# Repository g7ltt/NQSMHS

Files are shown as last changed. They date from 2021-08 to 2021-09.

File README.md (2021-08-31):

# NQSMHS

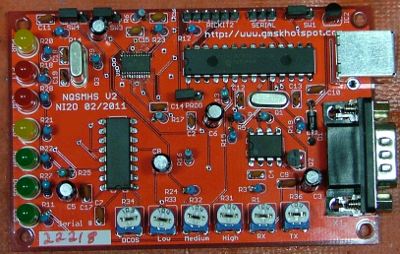
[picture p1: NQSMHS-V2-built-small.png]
finished board


Home of the D-STAR™ compatible Mini-HotSpot & Not Quite So Mini-HotSpot

Similar to the NQSMHS V1.1x series, the V2 board shares all the same facilities. The only changes are mechanical/cosmetic and with a few circuit flaws repaired.

Features include
Digital COS
DUTCH*Star HSA firmware compatible
"Satoshi" firmware V4.xx and V5.xx compatible
TTL serial port (for slow speed data)
S:N/RSSI (when used with relevant firmware/software)
USB firmware boot loader (when used with relevant firmware)
PICKit2 ICSP header
The NQSMHS-V2 is available in kit format. Lead time is usually 1 week but may change due to parts availability.

Unlike the 1.1x series of boards firmware is now provided Your board comes supplied with the DUTCH*Star PICBoot bootloader pre-installed. This will enable you to install the DUTCH*Star HSA firmware available from http://www.dutch-star.eu when coupled with the supplied firmware licence key.

REV V2
Nothing to report. All works as planned (when did that ever happen?!)

Please refer to the DUTCH*Star documentation for instructions on installing the firmware and drivers.

DIP switch settings are as follows;
SW1 (power)          Left = USB powered     Right = external 12V powered
PROG            installed = force bootloader mode
SW3               installed = RSSI enabled
SW4                       Left = RSSI enabled       Right = RSSI disabled
 Board layout, schematic and parts list can be found here.

MODS
Some users report very low transmit data levels emitting from the board. A quick fix for this is to cut the right leg of the TX pot.

Some users have reported that the PTT remains keyed long after the data has gone. This appears to be RF feedback holding the PTT transitor open. Place a 100pF (101) cap between the base of Q2 ground.

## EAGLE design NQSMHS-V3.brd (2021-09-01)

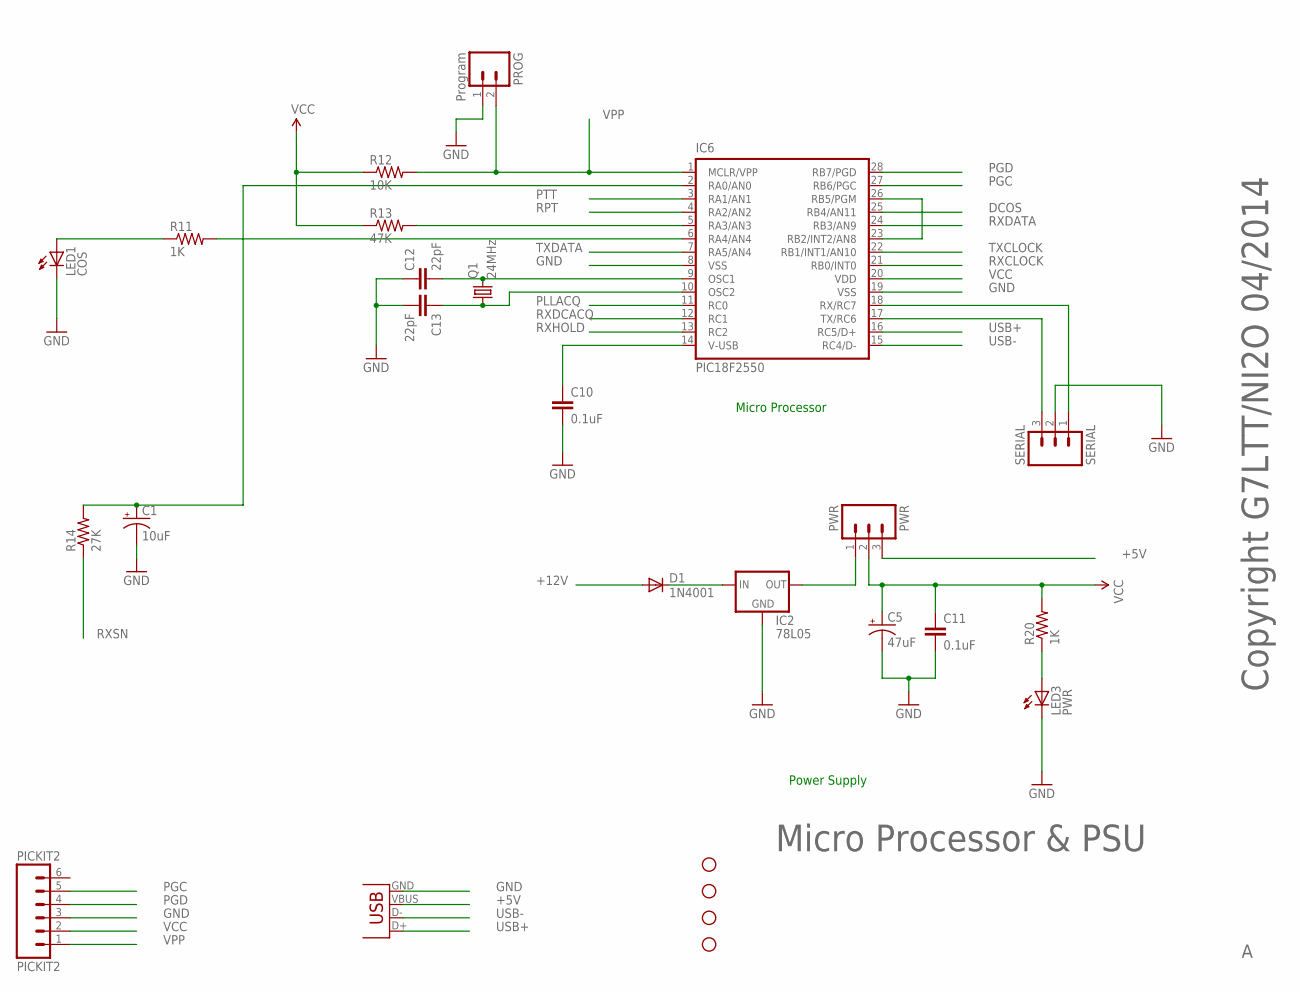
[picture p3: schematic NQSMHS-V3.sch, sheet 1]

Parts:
C1: 10uF; CPOL-RADIAL-10UF-25V
C5: 47uF; CPOL-RADIAL-10UF-25V
C10, C11: 0.1uF; C2.5-2
C12, C13: 22pF; C2.5-2
D1: 1N4001; DIODE-1N4001
IC2: 78L05; 78LXX
IC6: PIC18F2550; DIL28-3
J1: USBPTH; USB-B-PTH
JP7, JP8, JP9, JP10: STAND-OFF
LED1: COS; LED3MM
LED3: PWR; LED3MM
PICKIT2: PICKIT2; 1X06
PROG: Program; 1X02
PWR: PWR; 1X03
Q1: 24MHz; HC49US
R11, R20: 1K; 0207/2V
R12: 10K; 0207/2V
R13: 47K; 0207/2V
R14: 27K; 0207/2V
SERIAL: SERIAL; 1X03

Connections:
+5V: J1.VBUS, PWR.3
+12V: D1.A; also elsewhere on the board
DCOS: IC6.25 (RB4/AN11); also elsewhere on the board
GND: C1.2 (-), C5.2 (-), C10.2, C11.2, C12.1, C13.2, IC2.GND, IC6.8 (VSS), IC6.19 (VSS), J1.GND, LED1.K (C), LED3.K (C), PICKIT2.3, PROG.1, SERIAL.2; also elsewhere on the board
unnamed: D1.C, IC2.IN
unnamed: IC6.23 (RB2/INT2/AN8), IC6.26 (RB5/PGM)
unnamed: IC6.5 (RA3/AN3), R13.2
unnamed: IC6.6 (RA4/AN4), R11.2
unnamed: LED1.A, R11.1
unnamed: C12.2, IC6.9 (OSC1), Q1.2
unnamed: C13.1, IC6.10 (OSC2), Q1.1
unnamed: C10.1, IC6.14 (V-USB)
unnamed: IC2.OUT, PWR.1
unnamed: LED3.A, R20.1
PGC: IC6.27 (RB6/PGC), PICKIT2.5
PGD: IC6.28 (RB7/PGD), PICKIT2.4
PLLACQ: IC6.11 (RC0); also elsewhere on the board
PTT: IC6.3 (RA1/AN1); also elsewhere on the board
RPT: IC6.4 (RA2/AN2)
RX-232: IC6.18 (RX/RC7), SERIAL.1
RXCLOCK: IC6.21 (RB0/INT0); also elsewhere on the board
RXDATA: IC6.24 (RB3/AN9); also elsewhere on the board
RXDCACQ: IC6.12 (RC1); also elsewhere on the board
RXHOLD: IC6.13 (RC2); also elsewhere on the board
RXSN: R14.1; also elsewhere on the board
TX-232: IC6.17 (TX/RC6), SERIAL.3
TX/SN: C1.1 (+), IC6.2 (RA0/AN0), R14.2
TXCLOCK: IC6.22 (RB1/INT1/AN10); also elsewhere on the board
TXDATA: IC6.7 (RA5/AN4); also elsewhere on the board
USB+: IC6.16 (RC5/D+), J1.D+
USB-: IC6.15 (RC4/D-), J1.D-
VCC: C5.1 (+), C11.1, IC6.20 (VDD), PICKIT2.2, PWR.2, R12.1, R13.1, R20.2; also elsewhere on the board
VPP: IC6.1 (MCLR/VPP), PICKIT2.1, PROG.2, R12.2

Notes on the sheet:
Power Supply
Micro Processor
Micro Processor & PSU
Copyright G7LTT/NI2O 04/2014

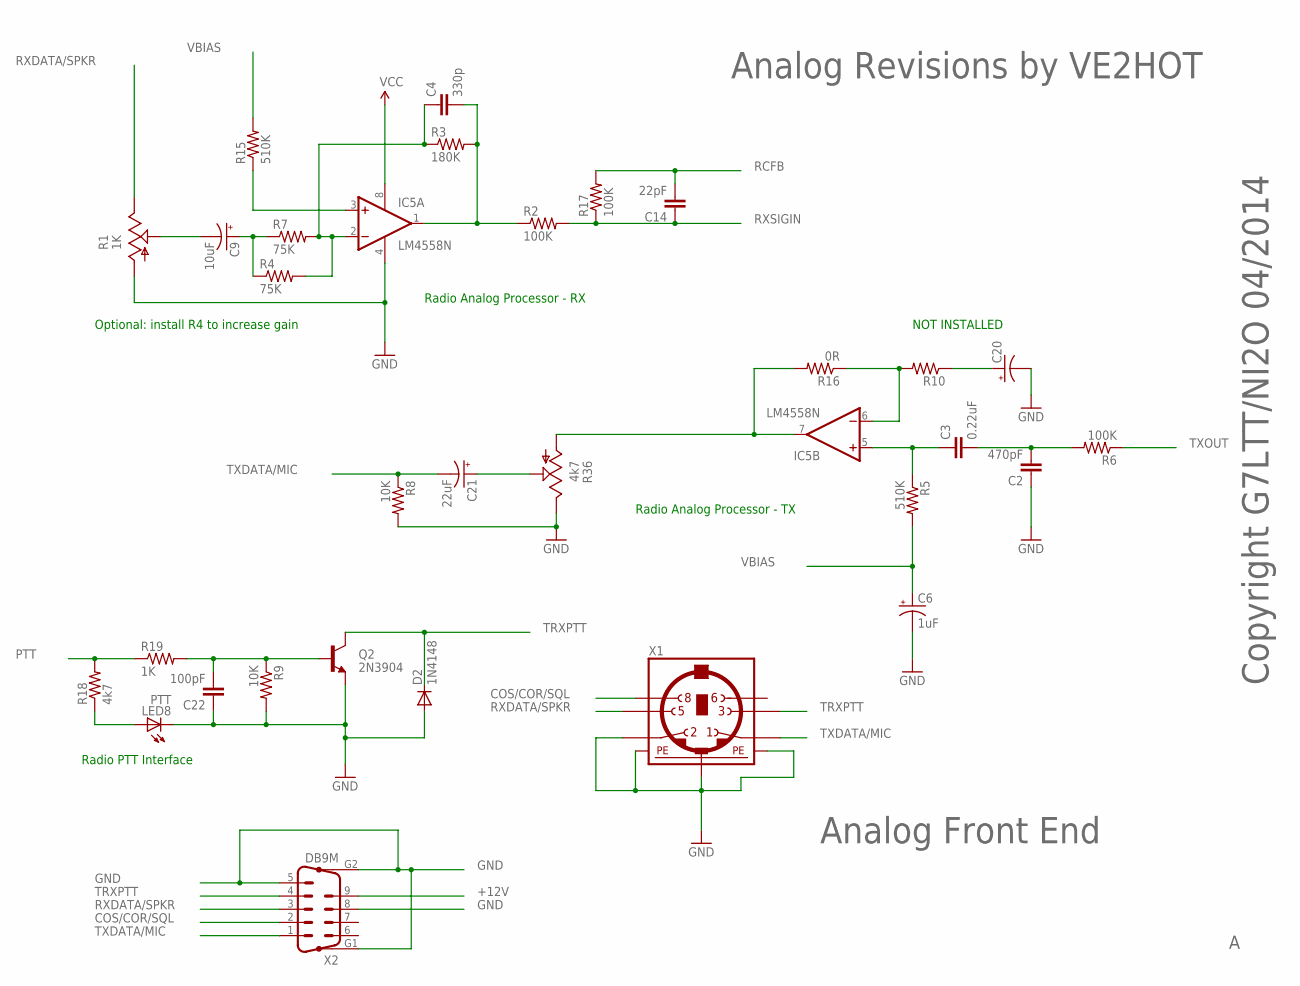
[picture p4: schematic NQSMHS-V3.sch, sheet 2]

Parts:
C2: 470pF; C2.5-2
C3: 0.22uF; C2.5-2
C4: 330p; C2.5-2
C6: 1uF; CPOL-RADIAL-10UF-25V
C9: 10uF; CPOL-RADIAL-10UF-25V
C14: 22pF; C2.5-2
C20: CAP_POLPTH2; CPOL-RADIAL-10UF-25V
C21: 22uF; CPOL-RADIAL-10UF-25V
C22: 100pF; C2.5-2
D2: 1N4148; DO35-10
IC5: LM4558N; DIL08
LED8: PTT; LED3MM
Q2: 2N3904; TO-92
R1: 1K; CA6V
R2, R6, R17: 100K; 0207/2V
R3: 180K; 0207/2V
R4, R7: 75K; 0207/2V
R5, R15: 510K; 0207/2V
R8, R9: 10K; 0207/2V
R10: R-US_0207/2V; 0207/2V
R16: 0R; 0207/2V
R18: 4k7; 0207/2V
R19: 1K; 0207/2V
R36: 4k7; CA6V
X1: MINI_DIN_6; M_DIN6
X2: DB9M; M09HP

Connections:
+12V: X2.9; also elsewhere on the board
COS/COR/SQL: X1.8, X2.2
GND: C2.1, C6.2 (-), C20.2 (-), C22.1, D2.A, IC5.4 (V-), LED8.K (C), Q2.1 (E), R1.A, R8.2, R9.2, R36.E, X1.2, X1.SH1 (PE1), X1.SH2 (PE2), X1.SH3 (PE3), X2.5, X2.8, X2.G1, X2.G2; also elsewhere on the board
unnamed: C2.2, C3.2, R6.2
unnamed: C22.2, Q2.2 (B), R9.1, R19.2
unnamed: LED8.A, R18.1
unnamed: C9.2 (-), R1.S
unnamed: IC5.7 (OUT), R16.2, R36.A
unnamed: C9.1 (+), R4.1, R7.1
unnamed: C4.2, IC5.1 (OUT), R2.1, R3.2
unnamed: C3.1, IC5.5 (+IN), R5.1
unnamed: C4.1, IC5.2 (-IN), R3.1, R4.2, R7.2
unnamed: IC5.6 (-IN), R10.2, R16.1
unnamed: C20.1 (+), R10.1
unnamed: C21.1 (+), R36.S
unnamed: IC5.3 (+IN), R15.1
PTT: R18.2, R19.1; also elsewhere on the board
RCFB: C14.2, R17.2; also elsewhere on the board
RXDATA/SPKR: R1.E, X1.5, X2.3
RXSIGIN: C14.1, R2.2, R17.1; also elsewhere on the board
TRXPTT: D2.C, Q2.3 (C), X1.3, X2.4
TXDATA/MIC: C21.2 (-), R8.1, X1.1, X2.1
TXOUT: R6.1; also elsewhere on the board
VBIAS: C6.1 (+), R5.2, R15.2; also elsewhere on the board
VCC: IC5.8 (V+); also elsewhere on the board

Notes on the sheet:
Radio Analog Processor - RX
Radio PTT Interface
Radio Analog Processor - TX
Analog Front End
Copyright G7LTT/NI2O 04/2014
Analog Revisions by VE2HOT
Optional: install R4 to increase gain
NOT INSTALLED

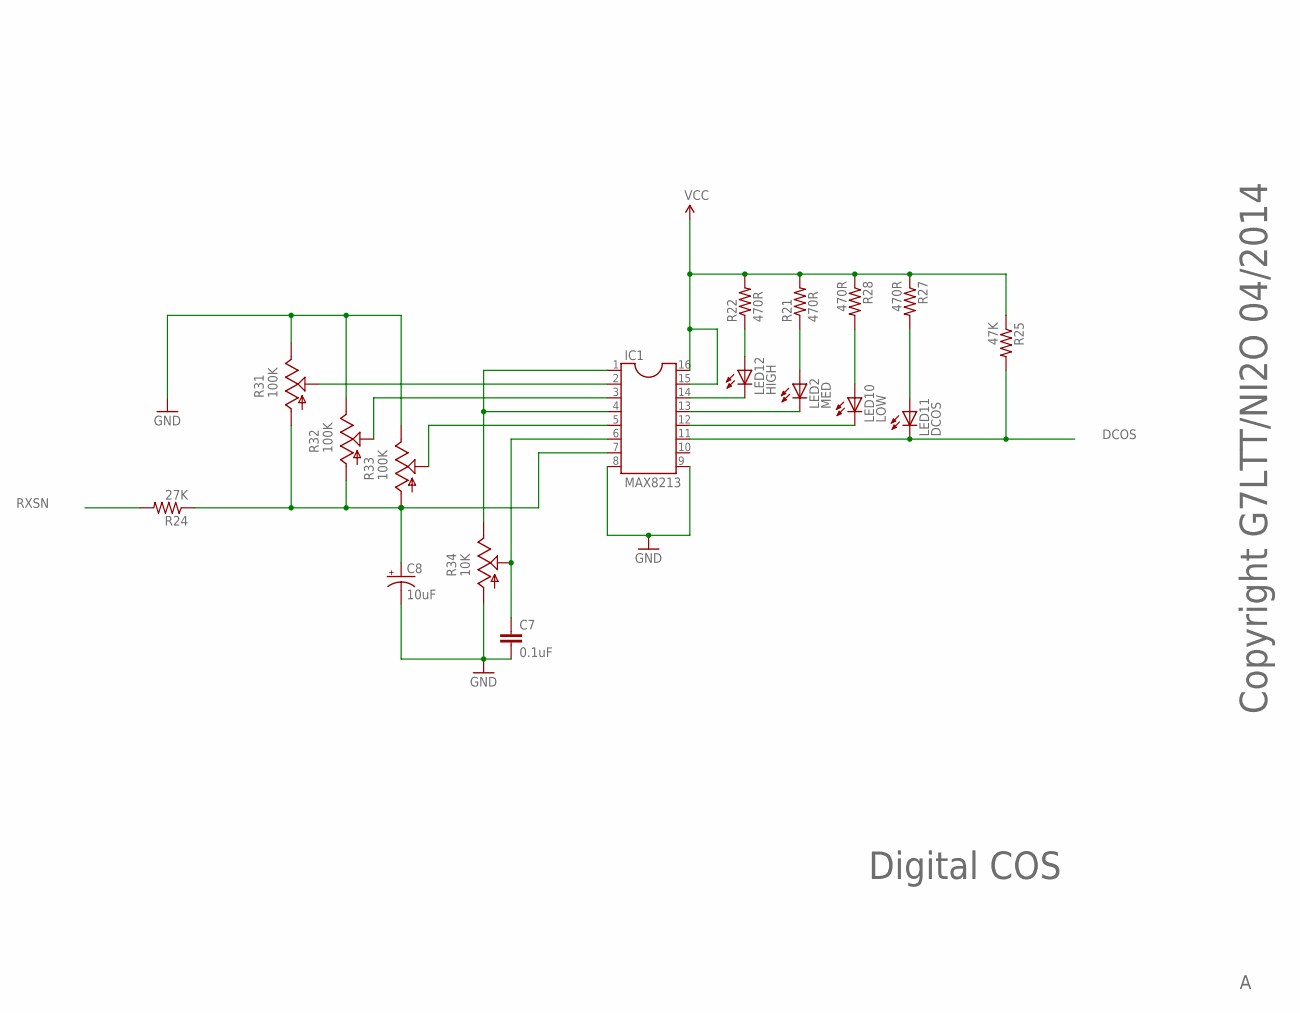
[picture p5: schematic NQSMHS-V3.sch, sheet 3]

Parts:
C7: 0.1uF; C2.5-2
C8: 10uF; CPOL-RADIAL-10UF-25V
IC1: MAX8213; DIL16
LED2: MED; LED3MM
LED10: LOW; LED3MM
LED11: DCOS; LED3MM
LED12: HIGH; LED3MM
R21, R22, R27, R28: 470R; 0207/2V
R24: 27K; 0207/2V
R25: 47K; 0207/2V
R31, R32, R33: 100K; CA6V
R34: 10K; CA6V

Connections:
DCOS: IC1.11, LED11.K (C), R25.2; also elsewhere on the board
GND: C7.2, C8.2 (-), IC1.8, IC1.9, R31.E, R32.E, R33.E, R34.A; also elsewhere on the board
unnamed: C7.1, IC1.6, R34.S
unnamed: IC1.14, LED12.K (C)
unnamed: LED12.A, R22.1
unnamed: IC1.13, LED2.K (C)
unnamed: LED2.A, R21.1
unnamed: IC1.12, LED10.K (C)
unnamed: LED11.A, R27.2
unnamed: LED10.A, R28.2
unnamed: IC1.2, R31.S
unnamed: IC1.3, R32.S
unnamed: IC1.5, R33.S
unnamed: IC1.1, IC1.4, R34.E
unnamed: C8.1 (+), IC1.7, R24.1, R31.A, R32.A, R33.A
RXSN: R24.2; also elsewhere on the board
VCC: IC1.15, IC1.16, R21.2, R22.2, R25.1, R27.1, R28.1; also elsewhere on the board

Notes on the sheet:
Digital COS
Copyright G7LTT/NI2O 04/2014

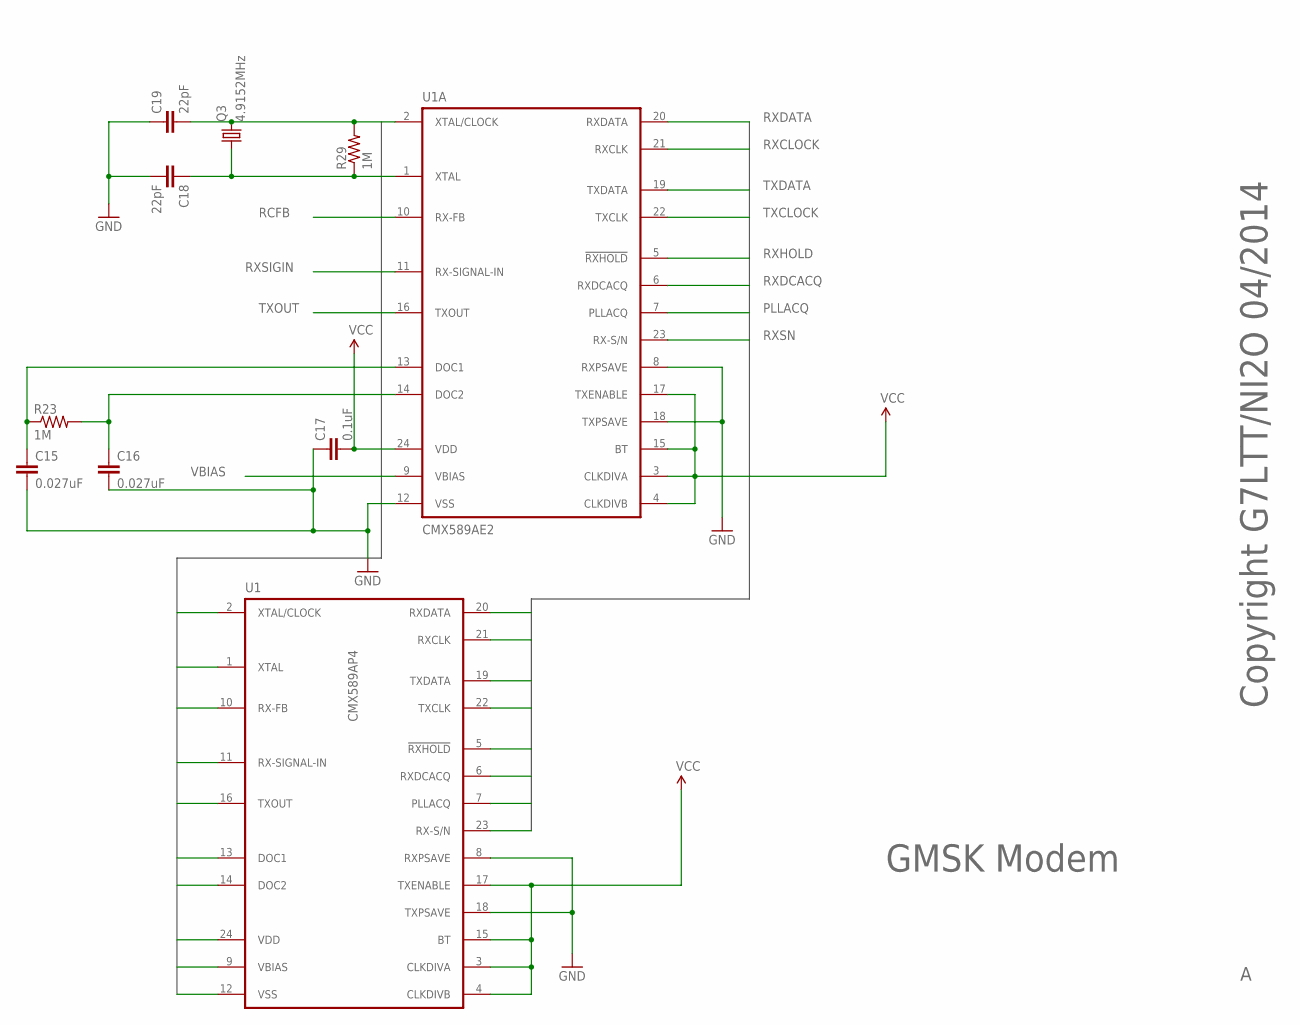
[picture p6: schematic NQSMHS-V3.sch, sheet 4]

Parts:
C15, C16: 0.027uF; C2.5-2
C17: 0.1uF; C2.5-2
C18, C19: 22pF; C2.5-2
Q3: 4.9152MHz; HC49US
R23, R29: 1M; 0207/2V
U1: CMX589AP4; DIL24-6
U1A: CMX589AE2; TSSOP24

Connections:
GND: C15.2, C16.2, C17.1, C18.2, C19.1, U1.8 (RXPSAVE), U1.12 (VSS), U1.18 (TXPSAVE), U1A.8 (RXPSAVE), U1A.12 (VSS), U1A.18 (TXPSAVE); also elsewhere on the board
unnamed: C15.1, R23.1, U1.13 (DOC1), U1A.13 (DOC1)
unnamed: C16.1, R23.2, U1.14 (DOC2), U1A.14 (DOC2)
unnamed: C18.1, Q3.1, R29.1, U1.1 (XTAL), U1A.1 (XTAL)
unnamed: C19.2, Q3.2, R29.2, U1.2 (XTAL/CLOCK), U1A.2 (XTAL/CLOCK)
PLLACQ: U1.7 (PLLACQ), U1A.7 (PLLACQ); also elsewhere on the board
RCFB: U1.10 (RX-FB), U1A.10 (RX-FB); also elsewhere on the board
RXCLOCK: U1.21 (RXCLK), U1A.21 (RXCLK); also elsewhere on the board
RXDATA: U1.20 (RXDATA), U1A.20 (RXDATA); also elsewhere on the board
RXDCACQ: U1.6 (RXDCACQ), U1A.6 (RXDCACQ); also elsewhere on the board
RXHOLD: U1.5 (!RXHOLD!), U1A.5 (!RXHOLD!); also elsewhere on the board
RXSIGIN: U1.11 (RX-SIGNAL-IN), U1A.11 (RX-SIGNAL-IN); also elsewhere on the board
RXSN: U1.23 (RX-S/N), U1A.23 (RX-S/N); also elsewhere on the board
TXCLOCK: U1.22 (TXCLK), U1A.22 (TXCLK); also elsewhere on the board
TXDATA: U1.19 (TXDATA), U1A.19 (TXDATA); also elsewhere on the board
TXOUT: U1.16 (TXOUT), U1A.16 (TXOUT); also elsewhere on the board
VBIAS: U1.9 (VBIAS), U1A.9 (VBIAS); also elsewhere on the board
VCC: C17.2, U1.3 (CLKDIVA), U1.4 (CLKDIVB), U1.15 (BT), U1.17 (TXENABLE), U1.24 (VDD), U1A.3 (CLKDIVA), U1A.4 (CLKDIVB), U1A.15 (BT), U1A.17 (TXENABLE), U1A.24 (VDD); also elsewhere on the board

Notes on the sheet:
GMSK Modem
Copyright G7LTT/NI2O 04/2014

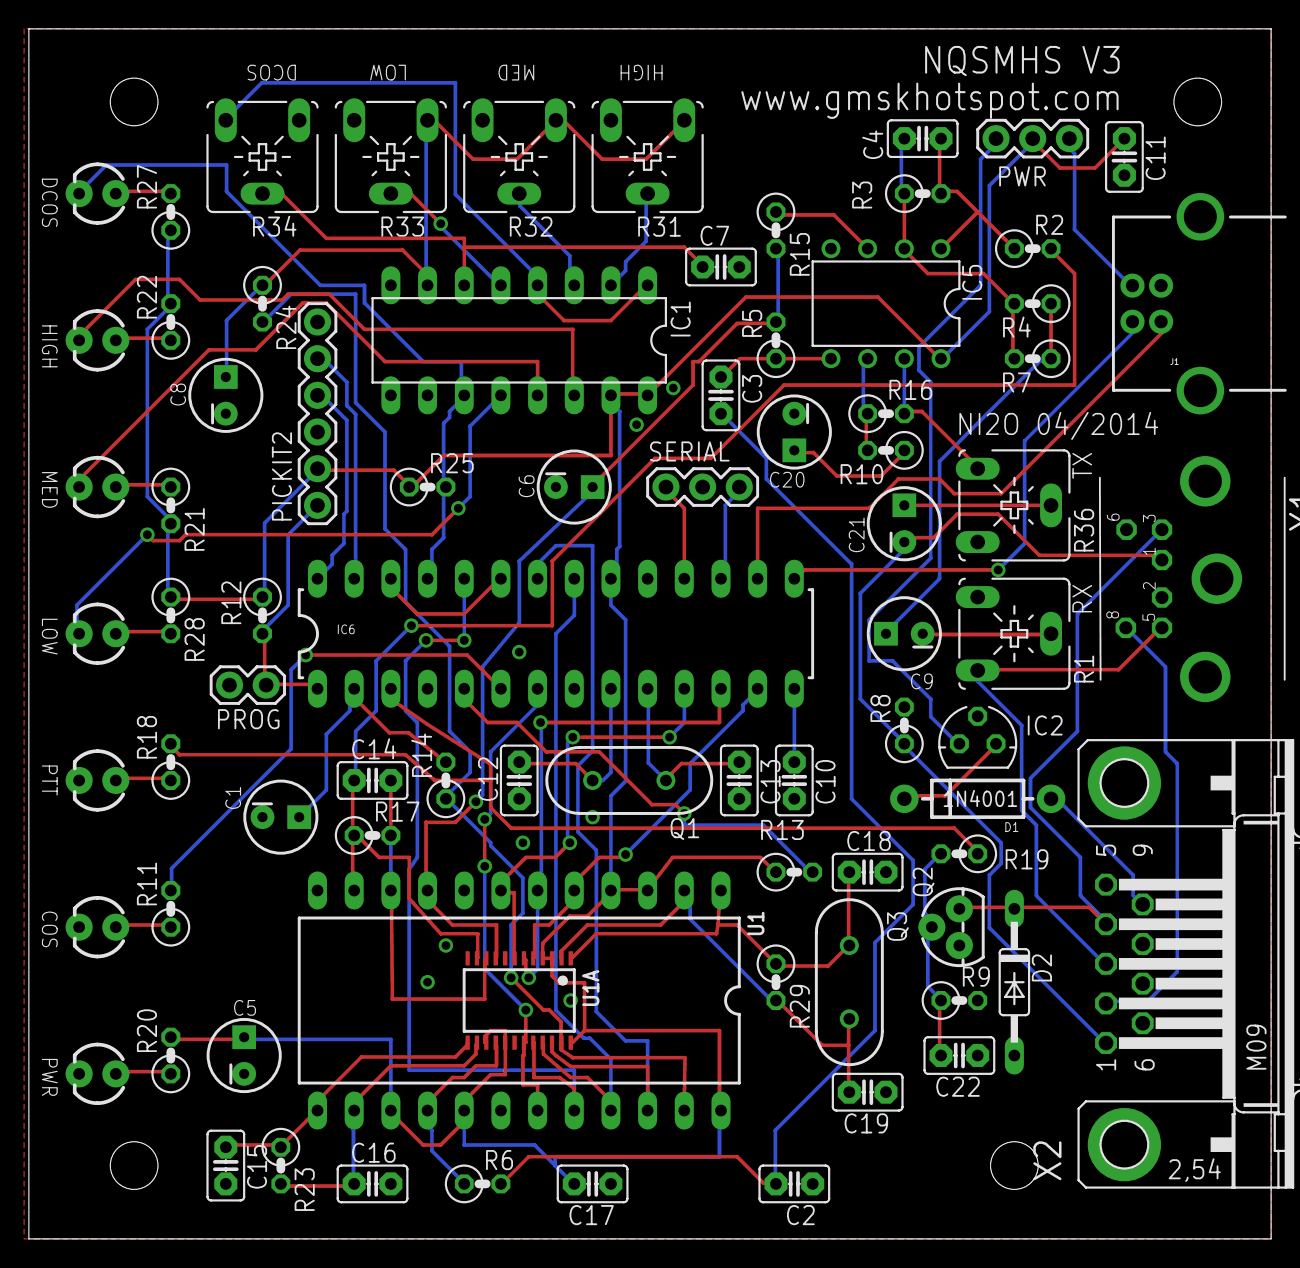
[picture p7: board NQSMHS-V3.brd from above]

Board: 2 copper layers, 86.0 x 83.8 mm, 84 parts (0 on the bottom side), 70 nets.
